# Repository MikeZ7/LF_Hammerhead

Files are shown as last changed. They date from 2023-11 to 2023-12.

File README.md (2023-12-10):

# LF_Hammerhead

---

## Description

Project of line following robot HAMMERHEAD

## Hardware

* Arduino Nano Every
* QTR-8RC IR Reflactance sensor
* HC-06 Bluetooth module
* Pololu Magnetic encoders
* Pololu 1:10 Motors
* DRV8833 Adafruit Motor driver

## First Version

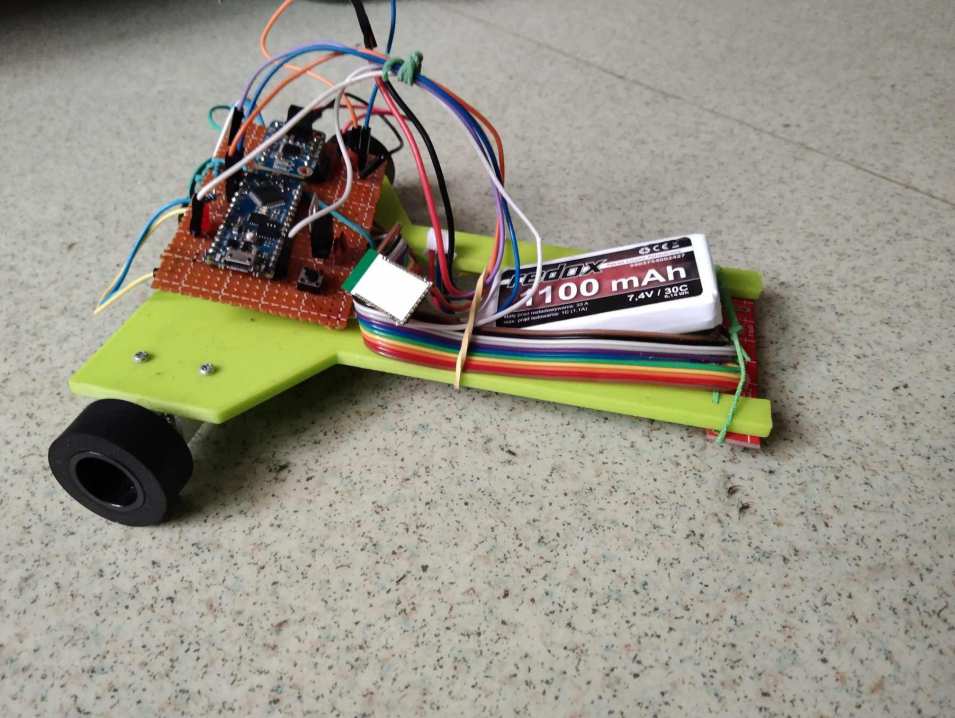
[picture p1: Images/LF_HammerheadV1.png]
LF_v1


## Current Version

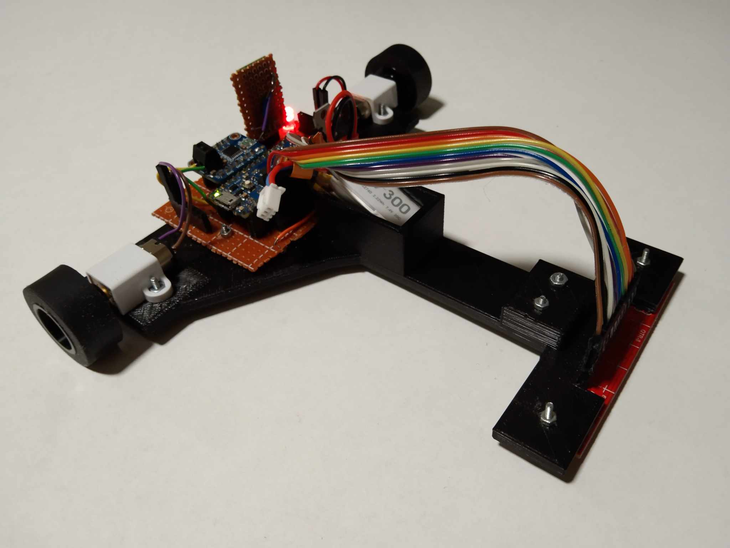
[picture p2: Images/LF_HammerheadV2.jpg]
LF_v2


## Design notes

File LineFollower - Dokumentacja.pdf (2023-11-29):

## Dokumentacja projektu

# Linefollower

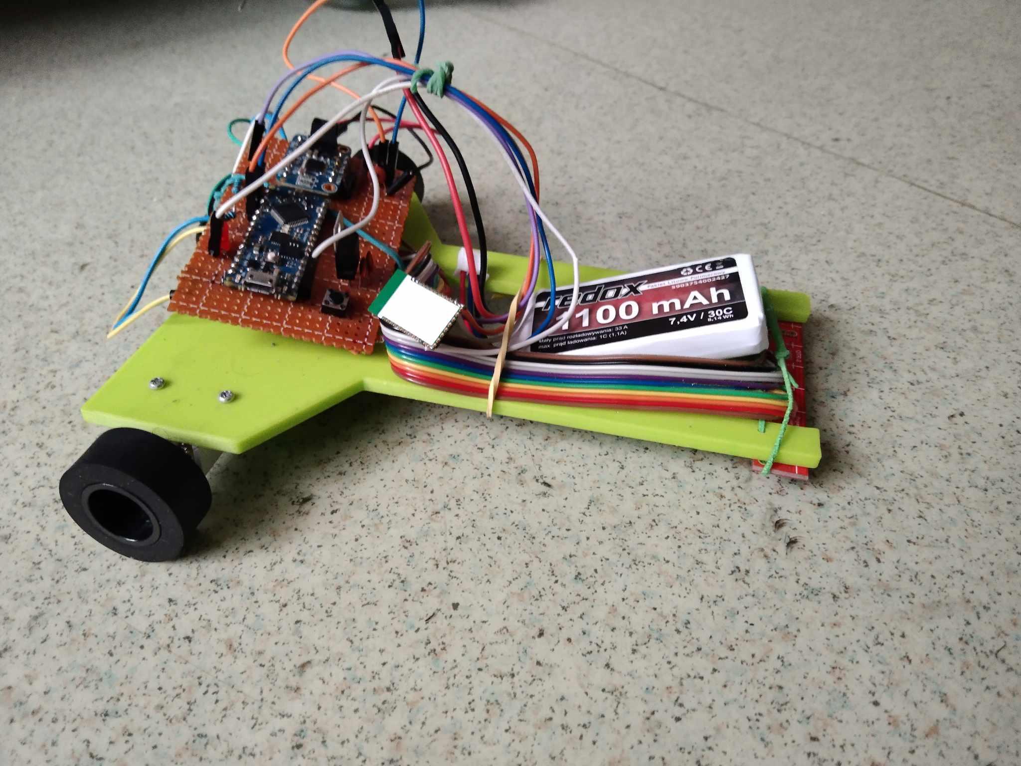
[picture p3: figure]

Jan Jędrzejowski

Michał Zelek

1) Założenia projektu:

Projekt Line Follower to automatyczny robot, który ma zdolność poruszania się po linii na podstawie odczytu sygnałów z czujników. Jest on obsługiwany za pomocą interfejsu graficznego, na którym wyświetlana jest jego trasa.

- Cel: Celem projektu jest stworzenie robota zdolnego do śledzenia i poruszania się wzdłuż linii na podłodze. Robot ma automatycznie dostosowywać swoje ruchy w zależności od odczytów z czujników. Ma komunikować się za pośrednictwem Bluetooth z komputerem
- Mechanizm poruszania się: Robot wyposażony dwa koła z indywidualnymi silnikami, umożliwiające mu poruszanie się po podłodze
- Czujniki linii: Robot wyposażony w czujniki odbiciowe, które będą odczytywać informacje o bieżącym położeniu linii. Będą one informować robota, czy linia jest z lewej czy z prawej strony.
- Algorytm śledzenia linii: Robot powinien mieć zaimplementowany algorytm, który będzie analizował odczyty z czujników i podejmował odpowiednie decyzje w celu utrzymania robota na linii (algorytm PID). Jego głównym celem jest skorygowanie ruchu robota, aby pozostał on na linii.
- Algorytm rysowania trasy: Robot powinien mieć zaimplementowany algorytm, który będzie analizował odczyty z enkoderów magnetycznych umieszczonych na obu kołach. Ma on za zadanie przeniesienie obrotów kół na płaszczyznę XY.
- Obudowa: Robot powinien być umieszczony w odpowiedniej obudowie, która zapewnia ochronę elektroniki oraz stabilność podczas poruszania się po linii.
- Źródło zasilania: Robot powinien mieć źródło zasilania, takie jak baterie, które dostarczą energię do napędów i elektroniki.
- Języki programowania: Do zaprogramowania robota zostaną użyte języki Python i C++

2) Schematy połączeń elektrycznych

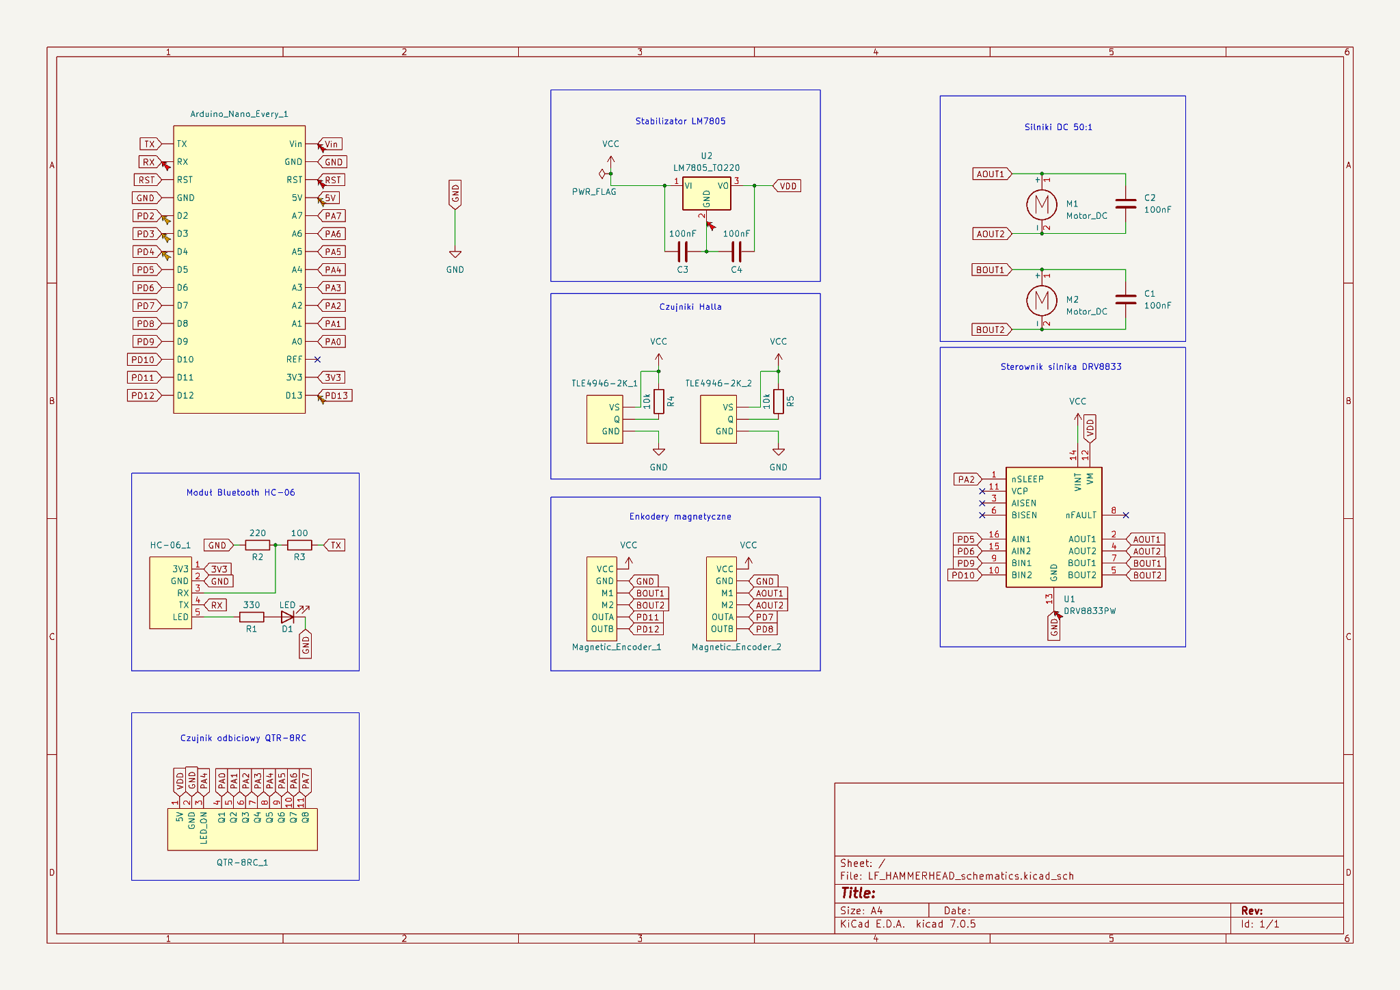
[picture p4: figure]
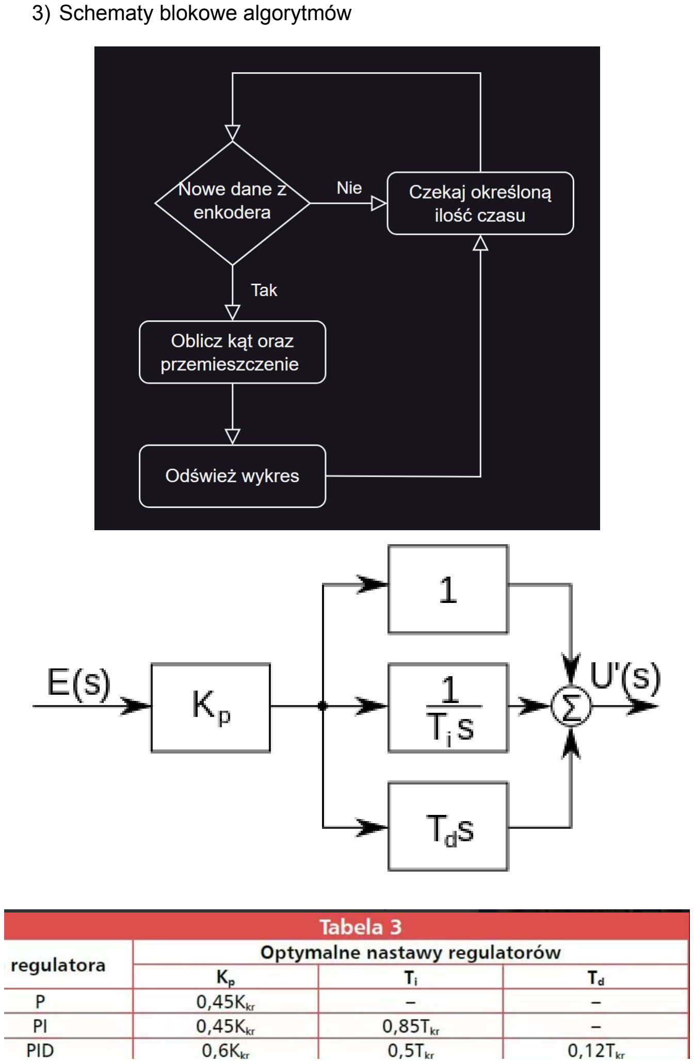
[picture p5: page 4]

3) Schematy blokowe algorytmów

4) Widok GUI

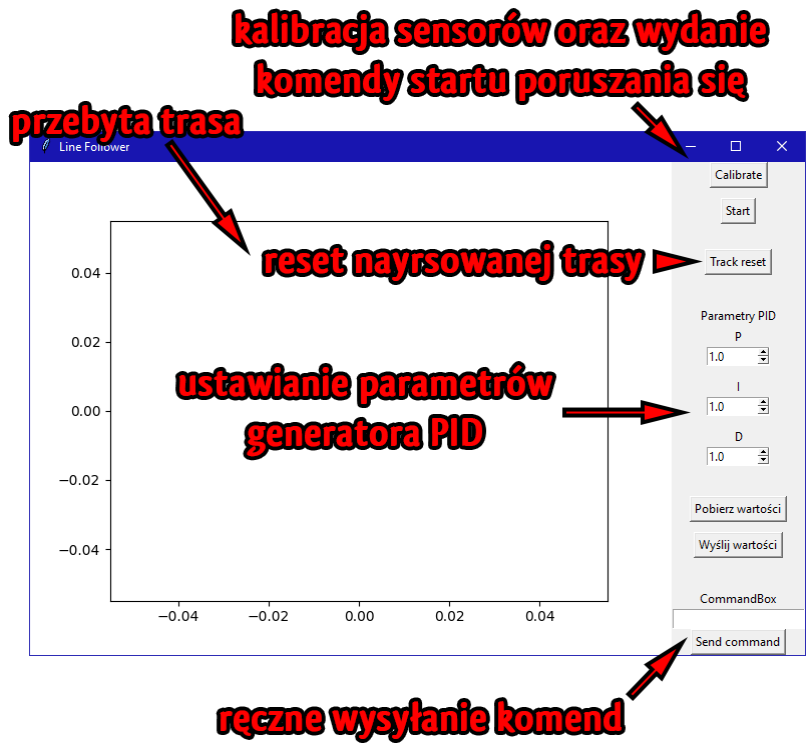
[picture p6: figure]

Interfejs jest minimalistyczny i intuicyjny w obsłudze.
Przebyta trasa rysowana jest w czasie rzeczywistym na płaszczyźnie XY.
Przed uruchomieniem robota należy dokonać kalibracji.
Możliwe jest także modyfikowanie zapisanych parametrów regulatora PID.

5) Opis uzyskanych rezultatów

Robot dosyć poprawnie podąża za linią. Można zaobserwować lekkie chybotanie się na boki. Powodem tego prawdopodobnie są nieidealny kontrast między czarną linią, a zielonym podłożem oraz nie najoptymalniejsze parametry PID.
Parametry PID otrzymano używając metody strojenia Zieglera-Nicholsa, jednak wyznaczone parametry nie były optymalne z uwagi na niedokładne obliczenie okresu oscylacji układu będącego na granicy stabilności.
Robot komunikuje się z interfejsem graficznym. Jego trasa jest rysowana w czasie rzeczywistym, ale nie odpowiada rzeczywistej trasie. Brak pokrycia trasy rysowanej z rzeczywistą wynika z błędów połączeniowych na płytce uniwersalnej, a najpewniej zwarcia wyjść kwadraturowych enkoderów magnetycznych, przez co na ilość otrzymywanych impulsów wpływa prędkość obrotowa silnika.

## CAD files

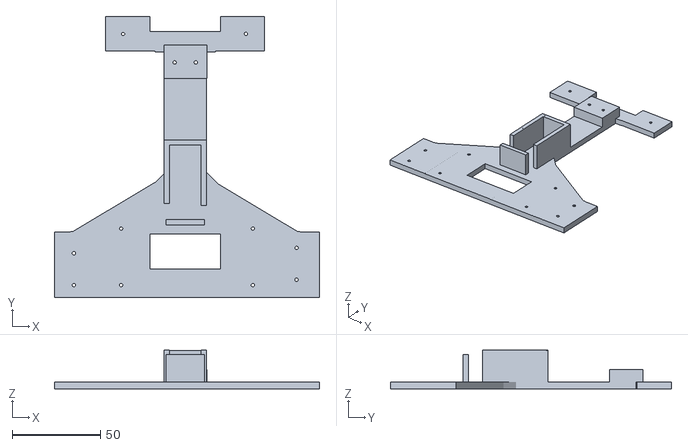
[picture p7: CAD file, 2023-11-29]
3D_model/LF_HAMMERHEADV1.stl
150.0 x 159.0 x 22.0

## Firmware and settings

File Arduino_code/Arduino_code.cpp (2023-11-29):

#include <Arduino.h>
#include <QTRSensors.h>
#include <EEPROM.h>

QTRSensors qtr;
const uint8_t sensorCount = 8;
uint16_t sensorValues[sensorCount];

//Motor setup
uint8_t motor_pins[4] = {5,6,9,10};
//default
uint8_t MOTOR_SPEED = 100;
uint8_t MAX_SPEED = 150;
//PID values
uint16_t maxError = 3500;
double lastError = 0;
const int goal = 3500;

//EEPROM
float kP = 0.00f;
float kD = 0.00f;
float kI = 0.00f;

int I = 0;

//startup flag
bool flag = 0;

//encoder impulses
volatile int count_l = 0;
volatile int count_r = 0;


void calibration(void){

    digitalWrite(LED_BUILTIN,HIGH);
    for (uint16_t i = 0; i < 400; i++)
    {
        qtr.calibrate();
    }
    digitalWrite(LED_BUILTIN, LOW); 

    //Printing raw values (max and min)
    for (uint8_t i = 0; i < sensorCount; i++)
    {
        Serial1.print(qtr.calibrationOn.minimum[i]);
        Serial1.print(' ');
    }
    Serial1.println();

    for (uint8_t i = 0; i < sensorCount; i++)
    {
        Serial1.print(qtr.calibrationOn.maximum[i]);
        Serial1.print(' ');
    }
    Serial1.println();
    Serial1.println();
    delay(1000);

}

void sendEncoders(){
    Serial1.print("r");
    Serial1.print(count_r);
    Serial1.print(" ");
    Serial1.print(count_l);
    Serial1.print("\n");
    count_l = 0;
    count_r = 0;
}


void adjustPIDparams(float KP, float KD = 0, float KI = 0){
    //Write to an eeprom addres
    EEPROM.put(0,KP);
    EEPROM.put(4,KD);
    EEPROM.put(8,KI);
    //write from addres to variables
    EEPROM.get(0,kP);
    EEPROM.get(4,kD);
    EEPROM.get(8,kI);

}


String btCommunication(void){
    String Str = "NoData";
    while(Serial1.available()){
           
        Str = Serial1.readString();    
    
    }
    return Str;  
}


void pdControl(uint16_t *s_values,const int goal,double l_error,int max_speed){

    while(true){
        if(digitalRead(3)==LOW){
            digitalWrite(2,LOW);
            break;
        }
        uint16_t position = qtr.readLineBlack(s_values);
        int currentError = goal - position;
        I = I+currentError;
        int adjustment = kP*currentError+kD*(currentError-l_error)+kI*I;
        lastError = currentError;
        analogWrite(5,constrain(max_speed-adjustment, 0, max_speed));
        analogWrite(9,constrain(max_speed+adjustment, 0, max_speed));
        sendEncoders();
    }
}

void motorStartup(int max_speed){

    for(uint8_t i = 0; i<max_speed; i++){
        analogWrite(5,i);
        analogWrite(9,i);
        delay(10);
    }
}

void getPID(){

    Serial1.print("kP: ");
    Serial1.print(kP,3);
    Serial1.print(" kD: ");
    Serial1.print(kD,3);
    Serial1.print(" kI: ");
    Serial1.print(kI,3);
    Serial1.println();
}

void setSpeed(uint8_t newMaxSpeed, uint8_t newMotorSpeed){
    EEPROM.put(20,newMotorSpeed);
    EEPROM.put(24,newMaxSpeed);
}

void getSpeed(){
    uint8_t max=0, motor=0;
    EEPROM.get(20,motor);
    EEPROM.get(24,max);
    Serial1.print("Motor speed: ");
    Serial1.print(max);
    Serial1.print(" Max speed: ");
    Serial1.print(motor);
    Serial1.println();
}

void setDefault(){
    //default speed
    EEPROM.put(20,150);
    EEPROM.put(24,100);
    //default PID variables
    EEPROM.put(0,5.64);
    EEPROM.put(4,0.07);
    EEPROM.put(8,0.26);
    EEPROM.get(0,kP);
    EEPROM.get(4,kD);
    EEPROM.get(8,kI);
    
}

void counter_r(){

  if(count_r==600)
    count_r=0;
  count_r++;
}


void counter_l(){

  if(count_l==600)
    count_l=0;
  count_l++;
}


void executeCommand(String str){
    String command;
    if(!(str=="NoData")){
        String bufor;
        int flag = 0;
        
        float P = 0.00f;
        float D = 0.00f;
        float I = 0.00f;
        
        for(int i = 0; i<str.length(); i++){

            if(str[i]==' '&&flag==0){     
                flag+=1;
                command = bufor;
                bufor = "";
            }
            else if(str[i]==' '&&flag==1){
                flag+=1;
                P = bufor.toFloat();
                bufor = "";
            }
            else if(str[i]==' '&&flag==2){
                flag+=1;
                D = bufor.toFloat();
                bufor = "";
            }
            else if(str[i]==' '&&flag==3){
                flag+=1;
                I = bufor.toFloat();
                bufor = "";
            }

            if(!(str[i]==' ')){
                bufor+=str[i];
            } 
        }

        if(command == "writePID"){
            adjustPIDparams(P,D,I);   
        }
        else if(command == "calibrate"){
            calibration();
        }
        else if(command == "start"){
            motorStartup(MOTOR_SPEED);
            pdControl(sensorValues,goal,lastError,MAX_SPEED);
        }
        else if(command == "getPID"){
            getPID();
        }
        else if(command == "setSpeed"){
            setSpeed(round(P),round(D));
        }
        else if(command == "getSpeed"){
            getSpeed();
        }
        else if(command == "setDefault"){
            setDefault();
        }
        else if(command == "getEncoder"){
            sendEncoders();
        }
        else{
            Serial1.println("No such command!");
        }
    }
     
}

void setup() {
  
  EEPROM.get(0,kP);
  EEPROM.get(4,kD);
  EEPROM.get(8,kI);

  MOTOR_SPEED = EEPROM.read(20);
  MAX_SPEED= EEPROM.read(24);
  
  //Encoders
  pinMode(11,INPUT);
  pinMode(12,INPUT);
  pinMode(7,INPUT);
  pinMode(8,INPUT);

  attachInterrupt(digitalPinToInterrupt(7),counter_l,CHANGE);
  attachInterrupt(digitalPinToInterrupt(8),counter_l,CHANGE);
  attachInterrupt(digitalPinToInterrupt(11),counter_r,CHANGE);
  attachInterrupt(digitalPinToInterrupt(12),counter_r,CHANGE);
  
  Serial.begin(9600);

  //Bluetooth setup
  Serial1.begin(9600); 
  
  //motor setup 
  for(uint8_t i = 0; i<sizeof(motor_pins); i++){
    pinMode(motor_pins[i],OUTPUT);
  }
  //DRV8833 SLP pin initialization
  pinMode(2,OUTPUT); 
  digitalWrite(2,HIGH);

  //button to stop PID
  pinMode(3,INPUT_PULLUP);

  //rotation direction
  digitalWrite(6,LOW);
  digitalWrite(10,LOW);

  //sensors setup
  QTRReadMode::On;
  qtr.setTypeRC();
  qtr.setSensorPins((const uint8_t[]){A7, A6, A5, A4, A3, A2, A1, A0}, sensorCount);
  qtr.setEmitterPin(4);
  pinMode(LED_BUILTIN, OUTPUT);

}

void loop() {
  String instruction = btCommunication();
  executeCommand(instruction);
 }

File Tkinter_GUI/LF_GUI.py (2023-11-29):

import matplotlib.pyplot as plt
import tkinter as tk
from matplotlib.backends.backend_tkagg import FigureCanvasTkAgg
from matplotlib.animation import FuncAnimation
import serial
import threading
from conversion import convert_impulses2_xy


root = tk.Tk()
root.title("Line Follower")

fig, ax = plt.subplots()
line, = ax.plot([], [], lw=2)
line2, = ax.plot([], [], lw=2)

x = [0]
y = [0]
alpha = 0
r = 1.453
L = 7.512
total_rotations = 600

recieved_data = []
data_to_send = []

# power_on = False

class CustomIterator:
    def __init__(self):
        self.current_frame = 0
    def __iter__(self):
        return self
    def __next__(self):
        return self.current_frame


def update_plot(i):
    global alpha
    if recieved_data:
        imp_L, imp_R = recieved_data.pop(0)
        x_mov, y_mov, alpha = convert_impulses2_xy(imp_R, imp_L, r, L, total_rotations, alpha)
        x.append(x[-1] + x_mov)
        y.append(y[-1] + y_mov)

    line.set_data(x, y)
    ax.relim()
    ax.autoscale_view()


# def toggle():
#     global power_on
#
#     if power_button.config('relief')[-1] == 'sunken':
#         power_button.config(relief="raised")
#         power_label.config(text="Robot OFF")
#         power_on = False
#         data_to_send.append("power=off")
#     else:
#         power_button.config(relief="sunken")
#         power_label.config(text="power=on")
#         power_on = True
#         data_to_send.append("power=on")


def calibrate():
    data_to_send.append("calibrate \n")


def start():
    data_to_send.append("start \n")


def track_reset():
    global x
    global y
    global alpha
    alpha = 0
    x.clear()
    y.clear()
    x.append(0)
    y.append(0)


def getPID():
    data_to_send.append("getPID \n")


def writePID():
    try:
        kP = pid_kP.get()
        kI = pid_kI.get()
        kD = pid_kD.get()
        data_to_send.append("writePID " + kP + " " + kI + " " + kD + " \n")
    except:
        print("Niepoprawne dane")


def command_send():
    command = command_box.get(1.0, "end-1c")
    command += " \n"
    if command:
        data_to_send.append(command)
        command_box.delete('1.0', tk.END)


def setup_connection():
    port="COM8"
    s = serial.Serial(port, 9600)  # Start communications with the bluetooth unit
    return s


s = setup_connection()


def recieve_data(*args):
    global recieved_data
    global s
    global data_to_send
    if (s.inWaiting() > 0):

        data = s.readline()
        if data:
            if data[-1] == " ":
                data = data[:-1]

            recieved = data.decode()

            if recieved[0] == "r":
                recieved = recieved[1:]
                splited = recieved.split(" ")
                element= [int(i) for i in splited]
                recieved_data.append(element)
            else:
                print("Odczyt: ", data)

            if recieved[0] == "k":
                splited = recieved.split(" ")
                pid_vP.set(float(splited[1]))
                pid_vI.set(float(splited[3]))
                pid_vD.set(float(splited[5]))




    if data_to_send:
        d_t_s = str.encode(data_to_send.pop(0))
        s.write(d_t_s)
        print("Wysyłanie: ", d_t_s)
    threading.Timer(0.01, recieve_data).start()


canvas = FigureCanvasTkAgg(fig, master=root)
canvas.get_tk_widget().pack(side=tk.LEFT, fill=tk.BOTH, expand=True)

iterator = CustomIterator()
ani = FuncAnimation(fig, update_plot, frames=iterator, interval=1)

button_frame = tk.Frame(root)
button_frame.pack(side=tk.LEFT, fill=tk.BOTH, expand=True)

# power_label = tk.Label(root, text = "Robot OFF")
# power_label.pack()
#
# power_button = tk.Button(root, text="Drive!", command=toggle, relief="raised")
# power_button.pack()

power_button = tk.Button(root, text="Calibrate", command=calibrate)
power_button.pack()

power_button = tk.Button(root, text="Start", command=start)
power_button.pack(pady=(10, 0))

track_reset = tk.Button(root, text="Track reset", command=track_reset)
track_reset.pack(pady=(25, 0))

pid_label = tk.Label(root, text = "Parametry PID")
pid_label.pack(pady=(30, 0))

pid_label_P = tk.Label(root, text = "P")
pid_label_P.pack()
pid_vP = tk.DoubleVar(value = 1.0)
pid_kP = tk.Spinbox(root, from_= 0, to = 100, width=8, increment=0.1, textvariable=pid_vP)
pid_kP.pack()

pid_label_I = tk.Label(root, text = "I")
pid_label_I.pack(pady=(10, 0))
pid_vI = tk.DoubleVar(value = 1.0)
pid_kI = tk.Spinbox(root, from_= 0, to = 100, width=8, increment=0.1, textvariable=pid_vI)
pid_kI.pack()

pid_label_D = tk.Label(root, text = "D")
pid_label_D.pack(pady=(10, 0))
pid_vD = tk.DoubleVar(value = 1.0)
pid_kD = tk.Spinbox(root, from_= 0, to = 100, width=8, increment=0.1, textvariable=pid_vD)
pid_kD.pack()

power_button = tk.Button(root, text="Pobierz wartości", command=getPID)
power_button.pack(pady=(30, 0))

power_button = tk.Button(root, text="Wyślij wartości", command=writePID)
power_button.pack(pady=(10, 0))

command_box_label = tk.Label(root, text = "CommandBox")
command_box_label.pack(pady=(30, 0))

command_box = tk.Text(root, height=1, width=16)
command_box.pack()

command_box_label_button = tk.Button(root, text="Send command", command=command_send)
command_box_label_button.pack()





recieve_data()
root.mainloop()
# while True:
#     root.update()


s.close()

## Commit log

2023-11-29 Uploading a current project version
    [LF_HAMMERHEADV6.stl, LF_HAMMERHEAD_schematics.kicad_sch]
2023-12-06 Uploading image for version 1
    [LF_HAMMERHEADV1.stl]
